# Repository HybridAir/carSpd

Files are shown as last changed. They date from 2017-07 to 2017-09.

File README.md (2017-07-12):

# carSpd

The carSpd (name in progress) is a work in progress device used to display your car's speed and other data in an easy to read, digital format. To do this, the device takes advantage of your car's speed and injector signals, much like the [MPGuino](http://ecomodder.com/wiki/index.php/MPGuino) project. Planned features include imperial/metric support, gas mileage and time display, and probably more depending on feature creep.

My main motivation for starting this project is so that I wont have to read the tiny kph numbers on my car's speedometer, since I just moved to Canada from the US with my car.

*This project is meant to be some kind of successor to the canceled carbt_v1 project. While their main functions are very different, they both serve the purpose of improving or adding new functions to my car.*

## Todo
- Finish programming
- Documentation
- Assemble

## Used Libraries
[Button](https://github.com/JChristensen/Button)

[EEPROMEx](https://github.com/thijse/Arduino-EEPROMEx)

[ST7032](https://github.com/tomozh/arduino_ST7032)

[RTC](https://github.com/Makuna/Rtc)

[RunningAverage](https://github.com/RobTillaart/Arduino/tree/master/libraries/RunningAverage)

[OneWire](https://github.com/PaulStoffregen/OneWire)

[DallasTemperature](https://github.com/milesburton/Arduino-Temperature-Control-Library)

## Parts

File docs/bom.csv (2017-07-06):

Qty | Device | Value | Package | Parts | Description | Digikey Part | Have
1 | DS18B20U |  | µSOP8 | U4 | Temp sensor | DS18B20U+-ND | 0
1 | DS3231S |  | 16-SOIC | IC3 | RTC | DS3231S#-ND | 0
3 | ZMM5V1 |  | SOD-80 | D6, D7, D8 | Backup zener diode for car inputs |  | 0
1 | resistor | 150 | res-0603 | R8 |  |  | 1
1 | resistor | 270 | res-0603 | R2 |  |  | 1
8 | capacitor | 0.1uf/100nf | cap-0805 | C2, C3, C6, C9, C10, C11, C15, C16 |  |  | 1
1 | resistor | 100k | res-0805 | R2 |  |  | 1
4 | resistor | 10k | res-0603 | R1, R5, R7, R11 |  |  | 1
1 | capacitor | 10nf | cap-0805 | C5 |  |  | 1
3 | capacitor | 10uf | cap-0603 | C1, C18, C7 |  |  | 1
3 | capacitor | 1uf | cap-0805 | C8, C12, C14 |  |  | 1
1 | resistor | 2.7k | res-0603 | R12 |  |  | 1
1 | transistor | 2n3904 | SOT23-3 | Q1 | Generic NPN BJT | 1727-4044-1-ND | 1
5 | resistor | 4.7k | res-0805 | R3, R4, R10, R15, R16 |  |  | 1
3 | resistor | 47k | res-0805 | R5, R6, R7 |  |  | 1
1 | ATMEGA328P-AU | ATMEGA328P_TQFP | TQFP32 | U1 |  | ATMEGA328P-AURCT-ND | 1
1 | Battery holder | CR1220 | 1220-SMD | B1 |  | BC501SM-ND | 1
1 | ERC1602-4 |  | ERC1602-4 | U3 | LCD from buydisplay |  | 1
1 | led | green | CHIPLED_0805 | LED2 | Power LED |  | 1
1 | led | red | CHIPLED_0805 | LED1 | Status LED |  | 1
4 | LED | white | CHIPLED_0805 | LED3, LED4, LED5, LED6 | Button indicator LEDs |  | 1
5 | tactile button |  | 3*6*2.5mm | S1, S2, S3, S4, S5 | Front and back reset buttons |  | 1
1 | CP2102-GMR |  | MLP-28 QFN | IC2 | USB to Serial | 336-1160-1-ND | 1
1 | 5p male header | CAR_INPUT | .1" pth right angle | SV1 | Car input connector | S1112EC-40-ND
1 | CBC2518T220M | 22uh | L3225M | L1 | inductor | 587-1616-1-ND
1 | CSTCE16M0V53-R0 | 16MHZ | RESONATOR-SMD | Y2 | resonator | 490-1198-1-ND
1 | FA-238 16.0000MB-C3 | 16MHZ | CRYSTAL-SMD-5X3 | Y1 | Optional crystal for U1 | SER3686CT-ND
2 | capacitor | 18pf | cap-0603 | C1, C4 | Load capacitors for optional Y1 | 490-9659-1-ND
3 | MM3Z5V1ST1G | 5.1V | SOD-323 | D1, D2, D3 | Primary car input zener diode | MM3Z5V1ST1GOSCT-ND
1 | 690-005-299-043 |  | USB-MINIB | JP2 | Mini USB B | 151-1206-1-ND
1 | capacitor | 22uf | cap-0805/0603 | C7 |  | 1276-6687-1-ND
1 | resistor | 52.3k | res-0603 | R9 | Calibration resisitor for IC1 | 311-52.3KHRCT-ND
1 | NSR0530HT1G |  | SOD-323 | D4 | Schottky diode | NSR0530HT1GOSCT-ND
1 | AZ1117 |  | SOT223 | U2 | Backup linear voltage reg | AZ1117CH-5.0TRG1DICT-ND
1 | 1N4148 |  | SOD-323 | D5 | Diode | 1N4148WXTPMSCT-ND
1 | MCP16301T-I/CHY |  | SOT23-6 | IC1 | DC buck converter | MCP16301T-I/CHYCT-ND

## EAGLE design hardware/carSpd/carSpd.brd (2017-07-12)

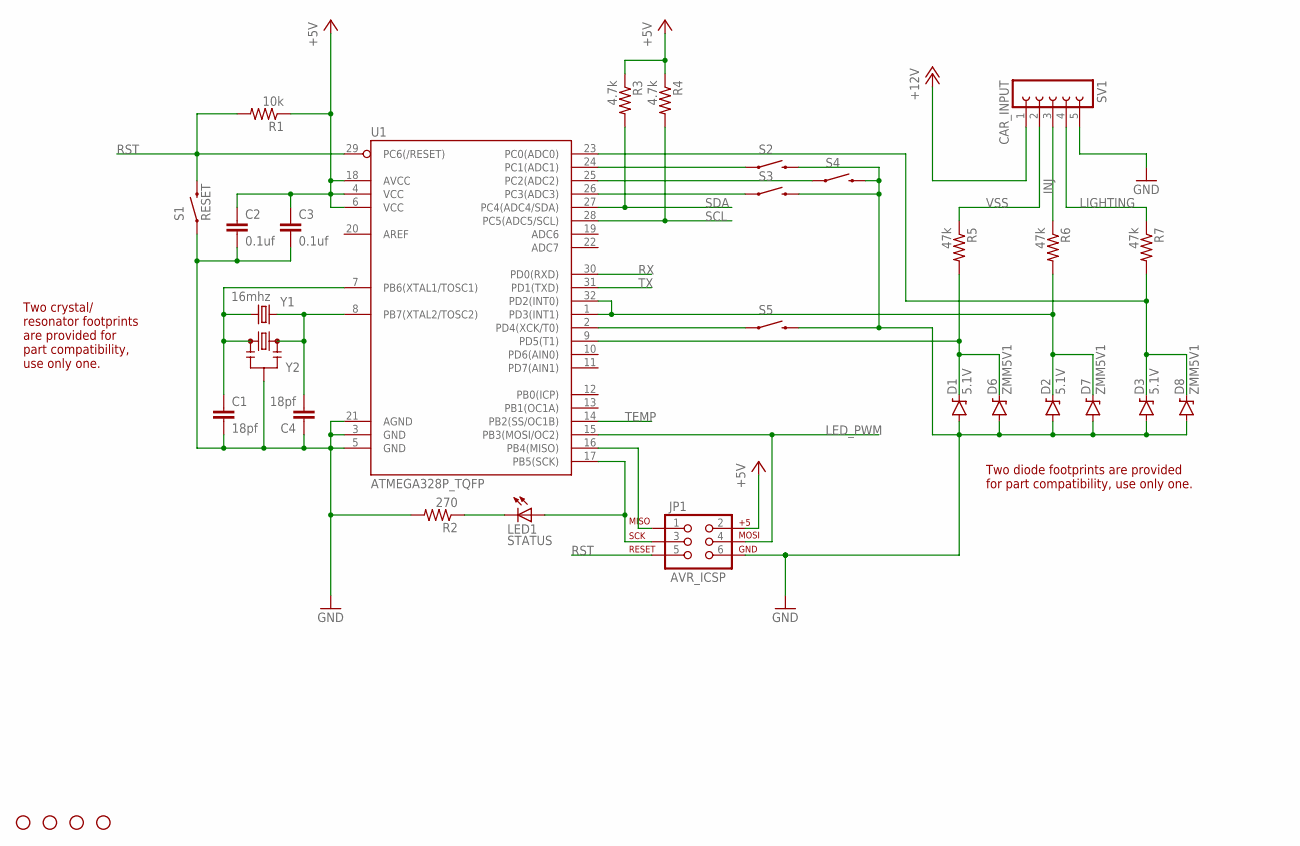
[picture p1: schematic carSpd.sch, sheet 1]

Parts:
C1, C4: 18pf; C0603K
C2, C3: 0.1uf; C0603K
D1, D2, D3: 5.1V; SOD-323
D6, D7, D8: ZMM5V1; SOD-80
H1, H2, H3, H4: STAND-OFF
JP1: AVR_ICSP; 2X3_TEST_POINTS
LED1: STATUS; CHIPLED_0805
R1: 10k; R0603
R2: 270; R0603
R3, R4: 4.7k; R0805
R5, R6, R7: 47k; R0805
S1: RESET; TACTILE-SWITCH-1101NE
S2, S3, S4, S5: SWITCH-MOMENTARY-2SMD-1101NE; TACTILE-SWITCH-1101NE
SV1: CAR_INPUT; FE05W
U1: ATMEGA328P_TQFP; TQFP32-08
Y1: 16mhz; CRYSTAL-SMD-5X3
Y2: 16MHZ; RESONATOR-SMD

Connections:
+5V: C2.1, C3.1, JP1.2, R1.1, R3.1, R4.1, U1.4 (VCC), U1.6 (VCC), U1.18 (AVCC); also elsewhere on the board
+12V: SV1.1; also elsewhere on the board
GND: C1.2, C2.2, C3.2, C4.1, D1.A, D2.A, D3.A, D6.A, D7.A, D8.A, JP1.6, R2.2, S1.1, S2.2, S3.2, S4.2, S5.2, SV1.5, U1.3 (GND), U1.5 (GND), U1.21 (AGND), Y2.2; also elsewhere on the board
INJ: R6.1, SV1.3
LED_PWM: JP1.4, U1.15 (PB3(MOSI/OC2)); also elsewhere on the board
LIGHTING: R7.1, SV1.4
unnamed: S2.1, U1.24 (PC1(ADC1))
unnamed: S4.1, U1.25 (PC2(ADC2))
unnamed: S3.1, U1.26 (PC3(ADC3))
unnamed: S5.1, U1.2 (PD4(XCK/T0))
unnamed: JP1.1, U1.16 (PB4(MISO))
unnamed: C1.1, U1.7 (PB6(XTAL1/TOSC1)), Y1.3 (2), Y2.1
unnamed: JP1.3, LED1.A, U1.17 (PB5(SCK))
unnamed: D2.C, D7.C, R6.2, U1.1 (PD3(INT1)), U1.32 (PD2(INT0))
unnamed: D3.C, D8.C, R7.2, U1.23 (PC0(ADC0))
unnamed: LED1.C, R2.1
unnamed: D1.C, D6.C, R5.2, U1.9 (PD5(T1))
unnamed: C4.2, U1.8 (PB7(XTAL2/TOSC2)), Y1.1, Y2.3
RST: JP1.5, R1.2, S1.2, U1.29 (PC6(/RESET)); also elsewhere on the board
RX: U1.30 (PD0(RXD)); also elsewhere on the board
SCL: R4.2, U1.28 (PC5(ADC5/SCL)); also elsewhere on the board
SDA: R3.2, U1.27 (PC4(ADC4/SDA)); also elsewhere on the board
TEMP: U1.14 (PB2(SS/OC1B)); also elsewhere on the board
TX: U1.31 (PD1(TXD)); also elsewhere on the board
VSS: R5.1, SV1.2

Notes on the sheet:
Two diode footprints are provided for part compatibility, use only one.
Two crystal/ resonator footprints are provided for part compatibility, use only one.

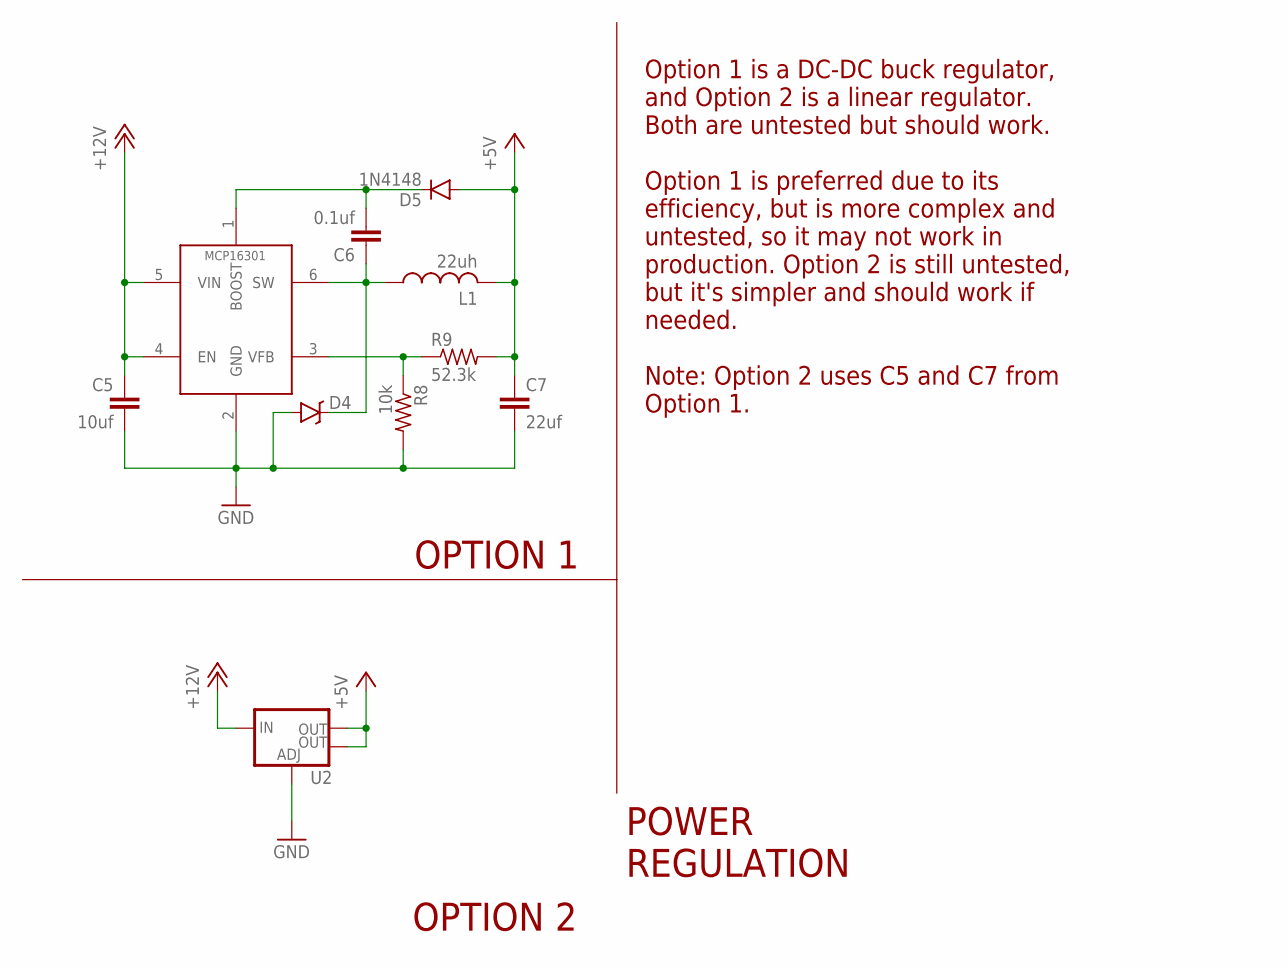
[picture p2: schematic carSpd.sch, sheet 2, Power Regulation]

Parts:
C5: 10uf; C0603K
C6: 0.1uf; C0603K
C7: 22uf; C0603K
D4: DIODE-SCHOTTKY-BAT20J; SOD-323
D5: 1N4148; SOD-323
IC1: MCP16301/H; SOT23-6
L1: 22uh; IND-1007/2518
R8: 10k; R0603
R9: 52.3k; R0603
U2: V_REG_LM1117SOT223; SOT223

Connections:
+5V: C7.1, D5.A, L1.P$2 (2), R9.2, U2.2 (OUT), U2.4 (OUT); also elsewhere on the board
+12V: C5.1, IC1.4 (EN), IC1.5 (VIN), U2.3 (IN); also elsewhere on the board
GND: C5.2, C7.2, D4.A, IC1.2 (GND), R8.2, U2.1 (ADJ); also elsewhere on the board
unnamed: IC1.3 (VFB), R8.1, R9.1
unnamed: C6.1, D4.C, IC1.6 (SW), L1.P$1 (1)
unnamed: C6.2, D5.C, IC1.1 (BOOST)

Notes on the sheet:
POWER REGULATION
Option 1 is a DC-DC buck regulator, and Option 2 is a linear regulator. Both are untested but should work. Option 1 is preferred due to its efficiency, but is more complex and untested, so it may not work in production. Option 2 is still untested, but it's simpler and should work if needed. Note: O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
OPTION 1
OPTION 2
MCP16301

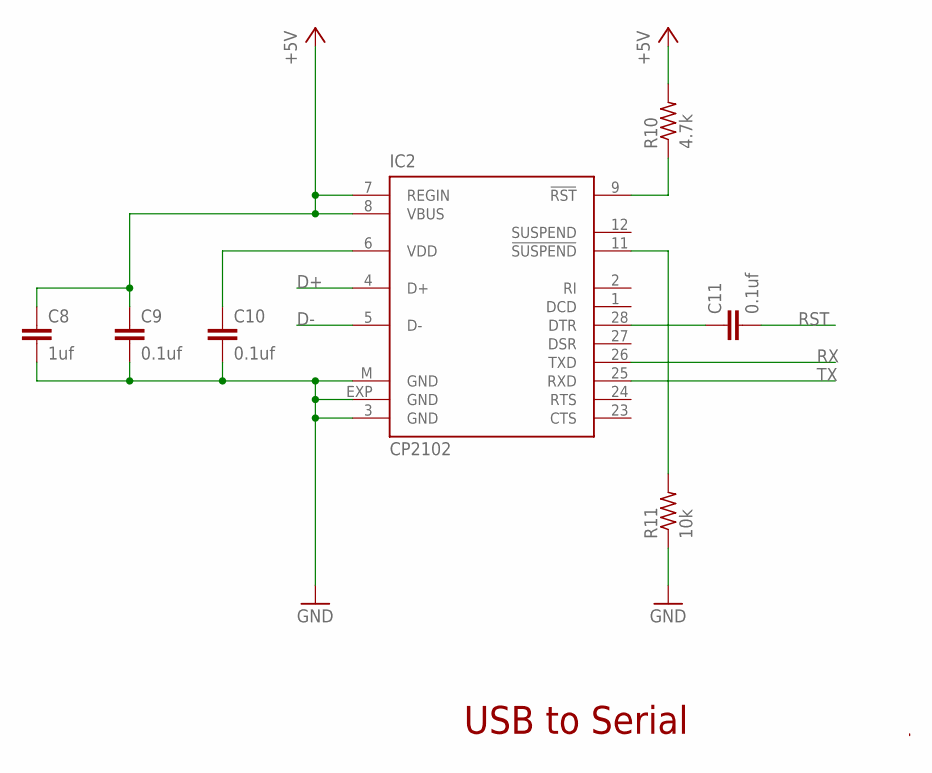
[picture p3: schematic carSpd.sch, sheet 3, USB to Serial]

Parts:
C8: 1uf; C0805K
C9, C10, C11: 0.1uf; C0603K
IC2: CP2102; MLP28
R10: 4.7k; R0805
R11: 10k; R0603

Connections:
+5V: C8.1, C9.1, IC2.7 (REGIN), IC2.8 (VBUS), R10.2; also elsewhere on the board
D+: IC2.4 (D+); also elsewhere on the board
D-: IC2.5 (D-); also elsewhere on the board
GND: C8.2, C9.2, C10.2, IC2.3 (GND), IC2.EXP (GND), IC2.M (GND), R11.1; also elsewhere on the board
unnamed: IC2.9 (!RST), R10.1
unnamed: IC2.11 (!SUSPEND), R11.2
unnamed: C11.1, IC2.28 (DTR)
unnamed: C10.1, IC2.6 (VDD)
RST: C11.2; also elsewhere on the board
RX: IC2.26 (TXD); also elsewhere on the board
TX: IC2.25 (RXD); also elsewhere on the board

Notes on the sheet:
USB to Serial

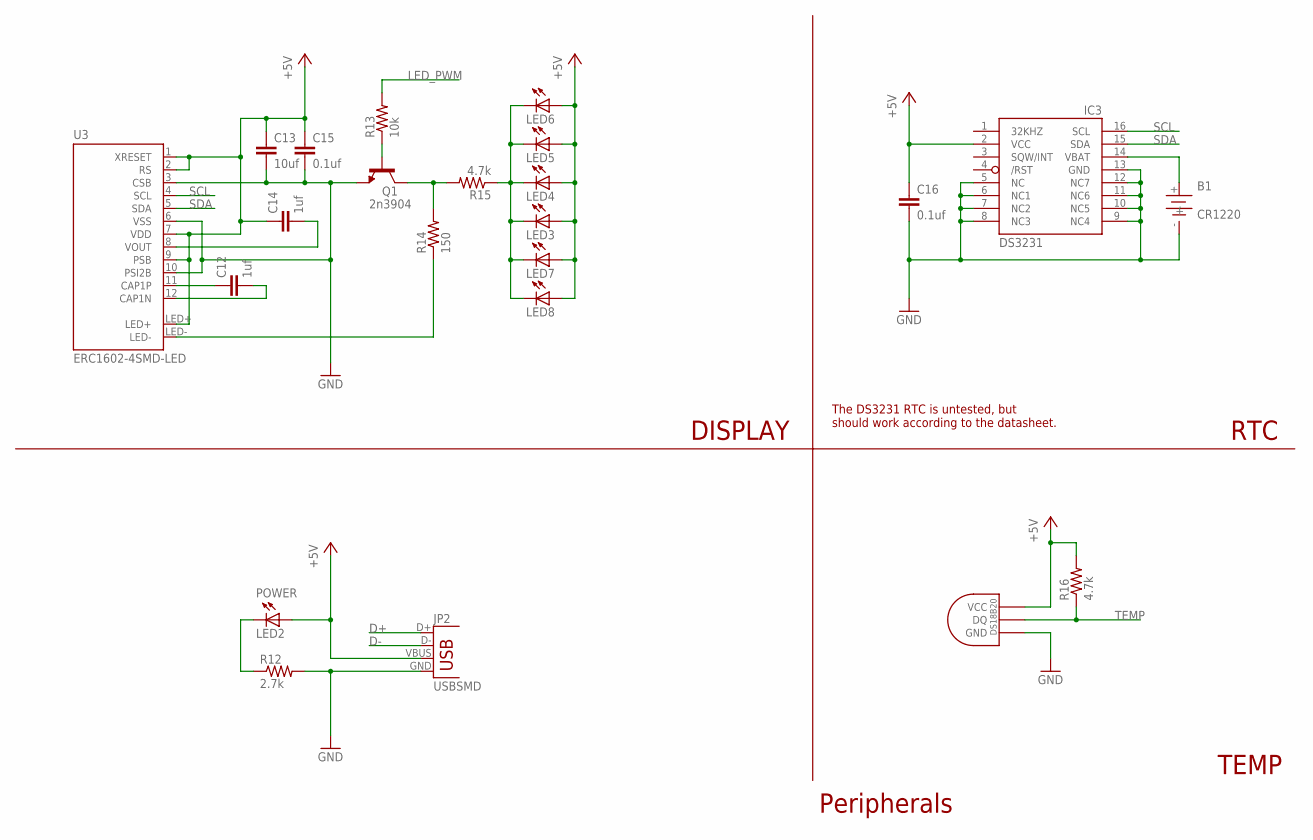
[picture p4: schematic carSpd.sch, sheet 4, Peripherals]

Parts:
B1: CR1220; 1220-SMD
C12, C14: 1uf; C0805K
C13: 10uf; C0603K
C15, C16: 0.1uf; C0603K
IC3: DS3231/SO; SO16W
JP2: USBSMD; USB-MINIB
LED2: POWER; CHIPLED_0805
LED3, LED4, LED5, LED6, LED7, LED8: LEDCHIPLED_0805; CHIPLED_0805
Q1: 2n3904; SOT23-3
R12: 2.7k; R0603
R13: 10k; R0603
R14: 150; R0603
R15, R16: 4.7k; R0805
U3: ERC1602-4SMD-LED; ERC1602-4_SMDLED
U4: DS1820; µSOP8

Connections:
+5V: C13.1, C14.1, C15.1, C16.1, IC3.2 (VCC), JP2.VBUS, LED2.A, LED3.A, LED4.A, LED5.A, LED6.A, LED7.A, LED8.A, R16.2, U3.1 (XRESET), U3.2 (RS), U3.7 (VDD), U3.9 (PSB), U3.LED+, U4.8 (VCC); also elsewhere on the board
D+: JP2.D+; also elsewhere on the board
D-: JP2.D-; also elsewhere on the board
GND: B1.-, C13.2, C15.2, C16.2, IC3.5 (NC), IC3.6 (NC1), IC3.7 (NC2), IC3.8 (NC3), IC3.9 (NC4), IC3.10 (NC5), IC3.11 (NC6), IC3.12 (NC7), IC3.13 (GND), JP2.GND, Q1.2 (E), R12.2, U3.3 (CSB), U3.6 (VSS), U3.10 (PSI2B), U4.4 (GND); also elsewhere on the board
LED_PWM: R13.2; also elsewhere on the board
unnamed: LED3.C, LED4.C, LED5.C, LED6.C, LED7.C, LED8.C, R15.1
unnamed: LED2.C, R12.1
unnamed: Q1.1 (B), R13.1
unnamed: C14.2, U3.8 (VOUT)
unnamed: Q1.3 (C), R14.2, R15.2
unnamed: R14.1, U3.LED-
unnamed: C12.1, U3.11 (CAP1P)
unnamed: C12.2, U3.12 (CAP1N)
unnamed: B1.+, IC3.14 (VBAT)
SCL: IC3.16 (SCL), U3.4 (SCL); also elsewhere on the board
SDA: IC3.15 (SDA), U3.5 (SDA); also elsewhere on the board
TEMP: R16.1, U4.1 (DQ); also elsewhere on the board

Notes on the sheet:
DISPLAY
RTC
TEMP
Peripherals
The DS3231 RTC is untested, but should work according to the datasheet.

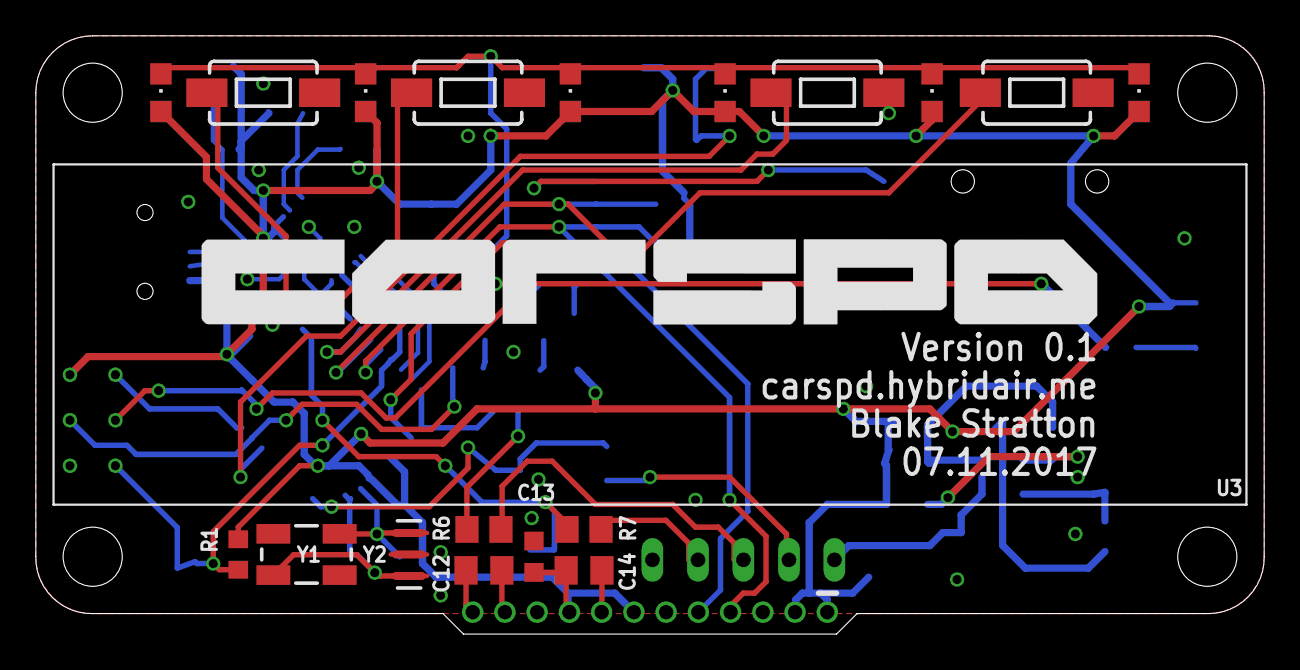
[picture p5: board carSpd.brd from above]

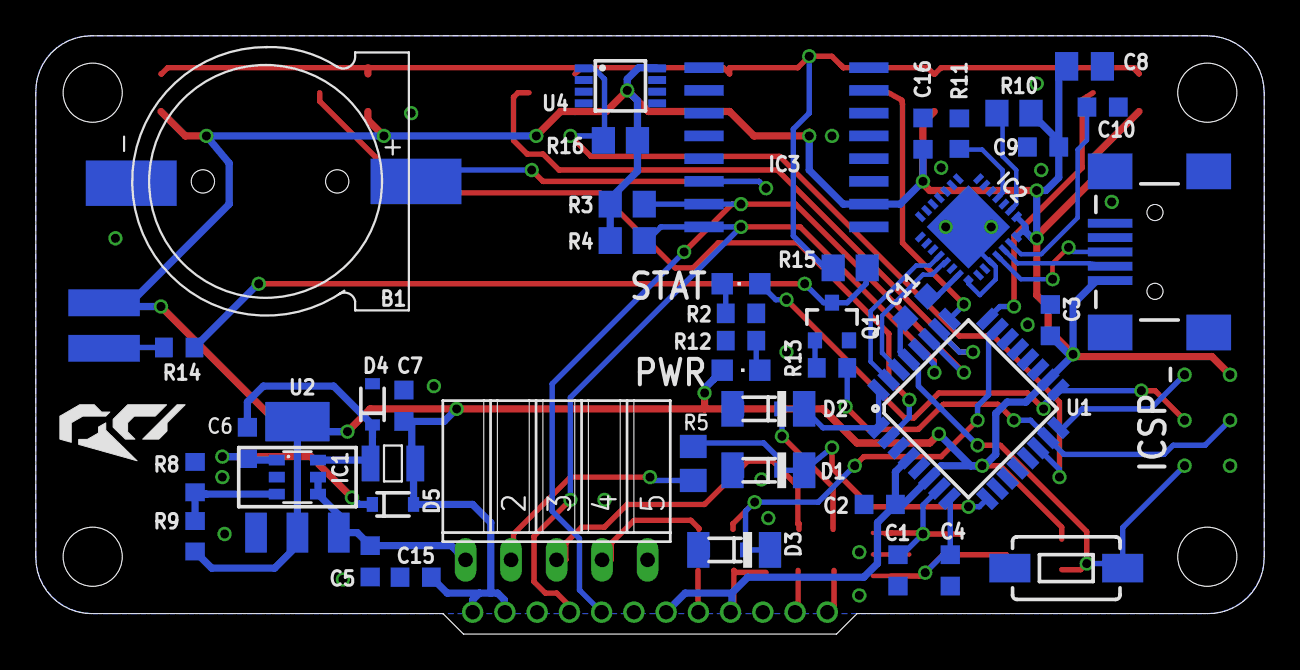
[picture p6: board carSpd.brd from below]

Board: 2 copper layers, 68.6 x 33.4 mm, 74 parts (50 on the bottom side), 43 nets.

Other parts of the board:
U$1: AR1
U$2: CARSPD

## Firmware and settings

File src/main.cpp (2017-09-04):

// carSpd main, currently being tested on an arduino uno
#include "main.hpp"

ST7032 lcd;

void setup() {
    Serial.begin(9600);     // used for debug and testing
Serial.println("starting");
    lcd.begin(16, 2);

    lcd.clear();
    controlInit();
    displayInit();
    carInit();
}


void loop() {
    //betterSpeed();
    monitorIO();
    displayUpdate();
}

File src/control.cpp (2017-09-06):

//handles all input and control stuff (buttons, settings, eeprom, backlight, etc)
#include "control.hpp"


// button debounce objects
Button btn1(BUTTON1_PIN, PULLUP, INVERT, DEBOUNCE_MS);
Button btn2(BUTTON2_PIN, PULLUP, INVERT, DEBOUNCE_MS);
Button btn3(BUTTON3_PIN, PULLUP, INVERT, DEBOUNCE_MS);
Button btn4(BUTTON4_PIN, PULLUP, INVERT, DEBOUNCE_MS);

// car illumination input running average object
RunningAverage backlightAvg(10);

// temperature sensor objects
OneWire oneWire(10);
DallasTemperature tempSensor(&oneWire);


// init
void controlInit() {
    // reset the eeprom to default values if a specific button is held during boot
    btn4.read();
    if(btn4.isPressed()) {
        resetEeprom();
    }
    else {                                                                      // else, get the existing settings out of eeprom
        initReadEeprom();
    }

    pinMode(BACKLIGHT_PIN, OUTPUT);     // set up the backlight output pin

    // prepare the temperature sensor
    tempSensor.begin();
    tempSensor.getAddress(tempSensorAddress, 0);        // find the sensor and get its address
    tempSensor.setResolution(tempSensorAddress, 10);    // use 10-bit resolution (accurate to .25 C)
    tempSensor.setWaitForConversion(false);            // make temperature reading non-blocking
    tempSensor.requestTemperatures();      // get the initial temperature value ready
}


// monitors everything, run this often
void monitorIO() {
    checkButtons();
    runAutoBacklight();
    checkTemp();

}


// reads all the settings out from eeprom, and sets initial variables
void initReadEeprom() {
    for(byte i = 0; i < sizeof(defaultEepromVals); i++) {                       // for each possible stored byte
        // read each byte into its corresponding function
        switch(i) {
            case SPEEDUNIT_ADDRESS:                                             // address 0: speed unit (mph/kph), as a bool
                setSpeedUnit(EEPROM.read(i));
                break;
            case LASTVIEWINDEX_ADDRESS:                                         // address 1: last displayed view index number, as a byte
                setView(EEPROM.read(i));
                break;
            case CONTRAST_ADDRESS:                                              // address 2: display contrast, as a byte
                setContrast(EEPROM.read(i));
                break;
            case LIGHTMODE_ADDRESS:                                             // address 3: backlight mode (auto/manual), as a bool
                setLightMode(EEPROM.read(i));
                break;
            case LIGHTLEVEL_ADDRESS:                                            //address 4: backlight brightness level, as a byte
                setBrightness(EEPROM.read(i));
                break;
            default:
                break;
        }
    }
}


// reads button states and does things as necessary
void checkButtons() {


    //TODO: hand off all buttons except for the menu button to the primary view system

     //btn1.read();
     //btn2.read();
     btn3.read();
    btn4.read();


    // if(btn1.wasPressed()) {
    //     toggleSpeedUnit();
    //     //printSpeed(getSpeed());
    // }

    if(btn3.wasPressed()) {
        int out = incBrightness();
        EEPROM.writeByte(LIGHTLEVEL_ADDRESS, out);                  // set the contrast and save it
        //EEPROM.writeByte(CONTRAST_ADDRESS, incContrast());                      // set the contrast and save it
        //Serial.print("up");
        //Serial.println(out);
    }

    if(btn4.wasPressed()) {
        int out = decBrightness();
        EEPROM.writeByte(LIGHTLEVEL_ADDRESS, out);                  // set the contrast and save it
        //EEPROM.writeByte(CONTRAST_ADDRESS, decContrast());                      // set the contrast and save it
        // Serial.print("down");
        // Serial.println(out);
    }

    // if(btn4.isPressed()) {                                                      // debug
    //     digitalWrite(13, HIGH);
    // }
    // else {
    //     digitalWrite(13, LOW);
    // }
}


// writes initial default eeprom values
void resetEeprom() {
    for(byte i = 0; i < sizeof(defaultEepromVals); i++) {
        EEPROM.updateByte(i, defaultEepromVals[i]);                             // write each byte in the data value array to the eeprom
        byte output = EEPROM.read(i);                                           // same function as readByte
        Serial.print("adress: ");
        Serial.println(i, DEC);
        Serial.print("input: ");
        Serial.println(defaultEepromVals[i], HEX);
        Serial.print("output: ");
        Serial.println(output, HEX);
        Serial.println("");
    }
}


// sets the current backlight mode to auto or manual, true for auto
void setLightMode(bool modeInput) {
    autoBacklight = modeInput;
}


// sets the backlight to a specific brightness level, give it the level index you want (0-7)
void setBrightness(uint8_t level) {
    if(!autoBacklight) {
        currentLevel = level;
        analogWrite(BACKLIGHT_PIN, brightnessLevel[currentLevel]);
    }
}


// increses the brightness level by 1, and returns the new level
uint8_t incBrightness() {
    if(!autoBacklight) {
        if(currentLevel >= 0 && currentLevel < (brightnessLevels - 1)) {
            currentLevel += 1;
        }
        setBrightness(currentLevel);
    }
    return currentLevel;
}


// decreases the brightness level by 1, and returns the new level
uint8_t decBrightness() {
    if(!autoBacklight) {
        if(currentLevel > 0 && currentLevel <= (brightnessLevels - 1)) {
            currentLevel -= 1;
        }
        setBrightness(currentLevel);
    }
    return currentLevel;
}
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

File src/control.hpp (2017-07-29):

#ifndef CONTROL_HPP
#define CONTROL_HPP

#include "main.hpp"
#include <Button.h>
#include <EEPROMex.h>
#include <RunningAverage.h>
#include <OneWire.h>
#include <DallasTemperature.h>


// button variables
#define BUTTON1_PIN A1
#define BUTTON2_PIN A2
#define BUTTON3_PIN A3
#define BUTTON4_PIN 4
#define PULLUP true
#define INVERT true
#define DEBOUNCE_MS 40


#define BACKLIGHT_PIN 11


// default eeprom data array, 5 different values are stored, each using a byte of space
// speedUnit bool, lastViewIndex, contrast, lightMode bool, lightLevel
#define SPEEDUNIT_ADDRESS   0
#define LASTVIEWINDEX_ADDRESS   1
#define CONTRAST_ADDRESS   2
#define LIGHTMODE_ADDRESS   3
#define LIGHTLEVEL_ADDRESS   4
static byte defaultEepromVals[6] = {0x00, 0x00, 0x1e, 0x00, 0x00};


#define CONTRASTMAX     48
#define CONTRASTMIN     16

//static uint8_t currentView = 0;       // the currently displayed view index


// backlight control variables
static bool autoBacklight = false;                                                      // default to auto backlight control mode
static uint8_t autoSampleInterval = 100;          // car lighting input sample rate
static uint32_t lastLightSampleTime = 0;        // the last time the car lighting input was sampled
static uint8_t currentAvg = 0;
static const uint8_t autoLightMin = 20;
static const uint8_t autoLightMax = 250;

static uint8_t currentBrightness = 255;
static const uint8_t brightnessLevels = 8;
static const uint8_t brightnessLevel[brightnessLevels] = {0, 4, 8, 16, 32, 64, 128, 255};
static uint8_t currentLevel = brightnessLevels - 1;


// temperature sensor variables
static DeviceAddress tempSensorAddress;
static const uint16_t tempInterval = 1000;
static uint32_t lastTempTime = 0;
static float temperatureC = 0;


// prototypes
static void checkButtons();
static void initReadEeprom();
static void resetEeprom();
static void runAutoBacklight();
static void setLightMode(bool modeInput);
static void setBrightness(uint8_t level);
static uint8_t incBrightness();
static uint8_t decBrightness();
static void checkTemp();

#endif

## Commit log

2017-06-21 Added manual eeprom reset functionality
    [control.cpp]
2017-06-24 Added a temperature sensor
2017-07-01 Added power regulator schematics
    [carSpd.brd, carSpd.sch]
2017-07-01 Added USB to serial schematics
    [carSpd.brd, carSpd.sch]
2017-07-01 Added peripheral schematics
    [carSpd.brd, carSpd.sch]
2017-07-02 Finished schematic, unverified
    [carSpd.brd, carSpd.sch]
2017-07-02 Removed the CH340G, supporting parts made it cost as much as a CP2102
    [carSpd.brd, carSpd.sch]
2017-07-02 Schematic cleanup
    [carSpd.brd, carSpd.sch]
2017-07-03 Modified and added parts list
    [bom.csv, carSpd.brd, carSpd.sch]
2017-07-05 Replaced power regulator circuits
    [carSpd.brd, carSpd.sch]
2017-07-05 Updated bom
    [bom.csv]
2017-07-05 Part listing complete
    [bom.csv]
2017-07-05 Corrected and verified schematics
    [carSpd.brd, carSpd.sch]
2017-07-06 Added digikey part numbers
    [bom.csv]
2017-07-08 Routing complete
    [carSpd.brd, carSpd.sch]
2017-07-09 Finished optimizations
    [carSpd.brd]
2017-07-12 PCB design complete
    [carSpd.brd, carSpd.sch]
2017-07-20 Remapped buttons
2017-07-20 Fixed button pin assignments
    [control.cpp, control.hpp]
2017-07-30 Added update timer bypass for unit changes
2017-08-29 Fixed speed calc math
    [carInput.hpp, main.cpp]
2017-09-04 Ugly code that barely works (going to fix)
    [carInput.hpp, main.cpp]

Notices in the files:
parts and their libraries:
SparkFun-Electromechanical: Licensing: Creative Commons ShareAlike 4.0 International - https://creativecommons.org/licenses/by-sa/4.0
